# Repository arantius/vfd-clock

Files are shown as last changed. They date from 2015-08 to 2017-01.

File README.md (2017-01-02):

A six digit clock based on the IV-22 Vacuum Fluorescent Display tube.

A learning project for me, using vacuum fluorescent display tubes and the STM32 processor for the first time.

I personally built one of these, and ended up with lots of spare parts.
I sold a _very limited_ number of kits, made up mostly of those spares.
I have no plans to assemble nor sell any further kits.
If you are interested in building this clock yourself, check out the Bill of Materials below, and the issues tab.

# Bill of Materials

| Part | Reference(s) | Value | Example Manufacturer Part Number |
| ---- | --- | ----- | --- |
| Battery Holder | BT1 | n/a | BU2032SM-BT-GTR |
| Chip Capacitor (0603) | C1, C2 | 4pF | - |
| Electrolytic Capacitor | C3, C4, C5, C6 | 47μF | 25YXF47MEFC5X11 |
| Chip Capacitor (0603) | C7 | 330pF | n/a |
| DC Jack | CON2 | - | EJ508A |
| DC Plug | - | - | PP3-002A |
| Diode | D1 | - | STPS130A |
| Inductor | L1 | 68μH | RCH8011NP-680L |
| Transistor | Q1, Q2 | - | MMBT4403LT1G |
| Resistor | R1 | 0.22Ω | LR1LJR22 |
| Chip Resistor (0603) | R2 | 12.4kΩ | - |
| Chip Resistor (0603) | R3 | 41.2kΩ | - |
| Chip Resistor (0603) | R4, R5 | 1kΩ | - |
| Variable Resistor | RV1 | 22kΩ | PVA2A223A01R00 [#1](https://github.com/arantius/vfd-clock/issues/1) |
| Piezo Speaker | SP1 | - | AT-1224-TWT-5V-2-R [#2](https://github.com/arantius/vfd-clock/issues/2) |
| Tactile Switch | SW1, SW2, SW3, SW4 | - | FSM6JSMA |
| Microcontroller | U1 | Maple Mini | - |
| 7-Segment Driver (16-SOIC) | U2, U3, U4, U5, U6, U7 | - | CD4056BM96 |
| Boost Regulator (8-SOIC) | U8 | - | MC34063ACD-TR |
| Volt Level Shifter (16-TSSOP) | U9, U10 | - | CD4504BPWR |
| VFD Display Tube | V1, V2, V3, V4, V5, V6 | - | IV-22 (a.k.a. IN-22, IИ-22) |
| Watch Crystal | X1 | 32.7680kHz | CFS-20632768DZBB |
| Optional GPS | - | - | NEO-6M |

Notes:
 * The official [Baite store on Aliexpress ](https://www.aliexpress.com/store/product/x/213957_1400682373.html) is a reliable source of cheap clone Maple Mini boards.
 * You'll also need 72 single-pin sockets for the tubes, these are most commonly/affordably available on eBay.  Look for "nixie pin socket".  (They're $0.20 each from DigiKey, but as low as $0.05 each in quantity from eBay.)  These sockets raise the tube off the board so that the vaccum seal "nipple" has some room.  Plus the ability to remove and replace tubes is nice!
 * The optional GPS module, if used, should have an 0.1" four pin header of: Vcc, RX, TX, GND in that order.  I used a "Ublox NEO-6M" module.
 * The battery (and its) holder is optional.  If you don't mind losing the time when you unplug you don't need it.

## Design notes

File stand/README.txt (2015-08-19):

For most uses, "Leg.svg" can simply be laser cut twice.  (But this is not
yet tested...)

The "Leg_Con2.svg" is a second shape specifically meant to fit over the power
cord connected to CON2, instead of CON1.  Since this connector came out of
a Dell laptop, you're probably using the standard barrel CON1 and can thus
ignore this file.

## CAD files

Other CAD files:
stand/VFD Clock Stand.skp

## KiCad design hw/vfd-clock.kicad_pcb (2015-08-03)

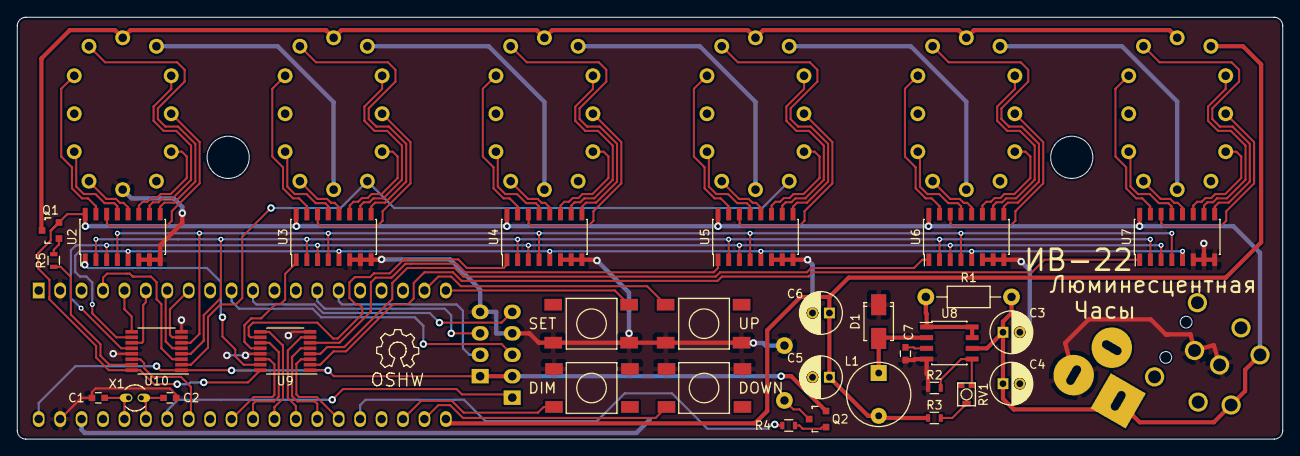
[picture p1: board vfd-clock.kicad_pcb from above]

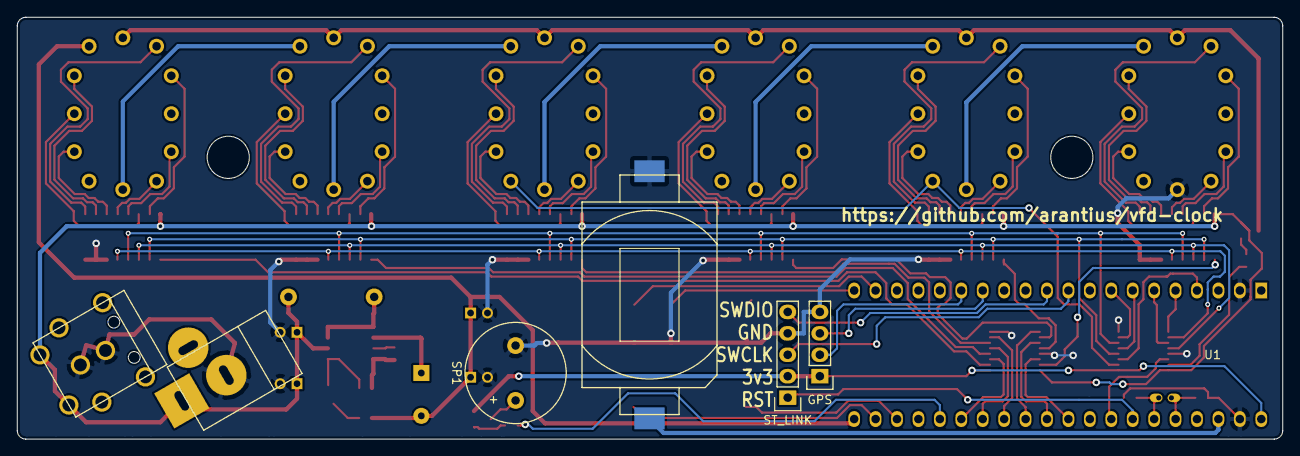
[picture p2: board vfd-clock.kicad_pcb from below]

Board: 2 copper layers, 150.0 x 50.0 mm, 46 parts (7 on the bottom side), 97 nets.

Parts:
BT1: COIN_BATT; BATT2032-1060TR
C1, C2: 4p; C_0603
C3, C4, C5, C6: 47u; C_Radial_D5_L11_P2
C7: 330p; C_0603
CON1: BARREL_JACK_2; JACK_ALIM
CON2: BARREL_JACK_2; OCT_JACK
D1: DIODESCH; Diode-SMA_Standard
L1: 68u; INDUCTOR_V
M1, M2: MountingHole_4-5mm; MountingHole_5mm
P1: ST_LINK; Pin_Header_Straight_1x05
P2: GPS; Pin_Header_Straight_1x04
Q1, Q2: PNP; MMBT4403L
R1: 0.22; Resistor_Horizontal_RM10mm
R2: 12.4k; R_0603
R3: 54.9k; R_0603
R4, R5: 1k; R_0603
RV1: 4k7; PVA2_POT
SP1: SPEAKER; AT-1224-TWT
SW1: SET; SMD_TACT_6mm
SW2: UP; SMD_TACT_6mm
SW3: DOWN; SMD_TACT_6mm
SW4: DIM; SMD_TACT_6mm
U1: Maple_Mini_(BTE14-07)
U2, U3, U4, U5, U6, U7: CD4056; SOIC-16_3.9x9.9mm_Pitch1.27mm
U8: MC34063; SOIC-8_3.9x4.9mm_Pitch1.27mm
U9, U10: CD4504; TSSOP-16_4.4x5mm_Pitch0.65mm
V1, V2, V3, V4, V5, V6: IV-22; DISP_IV-22_1PIN_SOCKET
X1: CRYSTAL; Crystal_Round_Vertical_3mm_BigPad

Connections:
/3v3: P1.2, P2.1, Q2.1, U1.40, U9.1, U10.1
/7v2: C5.1, C6.1, L1.2, R3.2, U1.21, V6.1
/19v5: C3.1, C4.1, CON1.1, CON2.1, Q1.1, R1.1, U2.16, U3.16, U4.16, U5.16, U6.16, U7.16, U8.6, U9.16, U10.16
/A1: U2.9, V1.11
/A2: U3.9, V2.11
/A3: U4.9, V3.11
/A4: U5.9, V4.11
/A5: U6.9, V5.11
/A6: U7.9, V6.11
/B1: U2.10, V1.2
/B2: U3.10, V2.2
/B3: U4.10, V3.2
/B4: U5.10, V4.2
/B5: U6.10, V5.2
/B6: U7.10, V6.2
/BTN_DIM: SW4.1, U1.23
/BTN_DN: SW3.1, U1.22
/BTN_SET: SW1.1, U1.20
/BTN_UP: SW2.1, U1.19
/BUZ: R4.2, U1.25
/C1: U2.11, V1.4
/C2: U3.11, V2.4
/C3: U4.11, V3.4
/C4: U5.11, V4.4
/C5: U6.11, V5.4
/C6: U7.11, V6.4
/D1: U2.12, V1.7
/D2: U3.12, V2.7
/D3: U4.12, V3.7
/D4: U5.12, V4.7
/D5: U6.12, V5.7
/D6: U7.12, V6.7
/DAH: U2.5, U3.5, U4.5, U5.5, U6.5, U7.5, U10.10
/DAL: U1.5, U10.9
/DBH: U2.3, U3.3, U4.3, U5.3, U6.3, U7.3, U10.12
/DBL: U1.6, U10.11
/DCH: U2.2, U3.2, U4.2, U5.2, U6.2, U7.2, U10.4
/DCL: U1.7, U10.5
/DDH: U2.4, U3.4, U4.4, U5.4, U6.4, U7.4, U10.6
/DDL: U1.8, U10.7
/DPH: U10.2, V2.5, V4.5
/DPL: U1.4, U10.3
/E1: U2.13, V1.8
/E2: U3.13, V2.8
/E3: U4.13, V3.8
/E4: U5.13, V4.8
/E5: U6.13, V5.8
/E6: U7.13, V6.8
/F1: U2.15, V1.10
/F2: U3.15, V2.10
/F3: U4.15, V3.10
/F4: U5.15, V4.10
/F5: U6.15, V5.10
/F6: U7.15, V6.10
/FIL1: V1.1, V2.6
/FIL2: V2.1, V3.6
/FIL3: V3.1, V4.6
/FIL4: V4.1, V5.6
/FIL5: V5.1, V6.6
/G1: U2.14, V1.3
/G2: U3.14, V2.3
/G3: U4.14, V3.3
/G4: U5.14, V4.3
/G5: U6.14, V5.3
/G6: U7.14, V6.3
/GND: BT1.2, C1.2, C2.2, C3.2, C4.2, C5.2, C6.2, C7.1, CON1.2, CON2.2, D1.1, P1.4, P2.4, R2.2, SP1.2, SW1.2, SW2.2, SW3.2, SW4.2, U1.2, U1.39, U2.6, U2.7, U2.8, U3.6, U3.7, U3.8, U4.6, U4.7, U4.8, U5.6, U5.7, U5.8, U6.6, U6.7, U6.8, U7.6, U7.7, U7.8, U8.4, U9.8, U9.13, U10.8, U10.13, V1.6
/GPS_RX: P2.2, U1.15
/GPS_TX: P2.3, U1.14
/GRID: Q1.3, V1.12, V2.12, V3.12, V4.12, V5.12, V6.12
/GRIDH: R5.2, U10.15
/GRIDL: U1.33, U10.14
/REG_HI: R1.2, U8.1, U8.7, U8.8
/RST: P1.1, U1.34
/STROBE1H: U2.1, U9.15
/STROBE1L: U1.31, U9.14
/STROBE2H: U3.1, U9.12
/STROBE2L: U1.30, U9.11
/STROBE3H: U4.1, U9.10
/STROBE3L: U1.29, U9.9
/STROBE4H: U5.1, U9.6
/STROBE4L: U1.28, U9.7
/STROBE5H: U6.1, U9.4
/STROBE5L: U1.27, U9.5
/STROBE6H: U7.1, U9.2
/STROBE6L: U1.26, U9.3
/SWCLK: P1.3, U1.10
/SWDIO: P1.5, U1.11
/Vbat: BT1.1, U1.38
unnamed: C1.1, U1.36, X1.1
unnamed: C2.1, U1.35, X1.2
unnamed: C7.2, U8.3
unnamed: D1.2, L1.1, U8.2
unnamed: Q1.2, R5.1
unnamed: Q2.2, R4.1
unnamed: Q2.3, SP1.1
unnamed: R2.1, RV1.1, U8.5
unnamed: R3.1, RV1.2

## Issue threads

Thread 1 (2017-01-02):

The trimpot is tiny

arantius, 2017-01-02:
As part of the voltage regulator circuit, there is a variable resistor/trimpot.  I sourced this part sight unseen across the internet, and the selected part is _really tiny_.  So small it's hard to get a screwdriver to turn it.  A bigger trimpot would be nice.

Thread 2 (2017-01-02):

The speaker doesn't fit.

arantius, 2017-01-02:
The footprint in the PCB and the selected piezo speaker aren't quite the same size.  The PCB holes are just a bit too far apart for part `AT-1224-TWT-5V-2-R`'s pins to fit correctly.

The PCB footprint should be fixed, or a part with pins that line up should be selected.

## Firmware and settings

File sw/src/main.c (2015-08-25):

/*
Copyright (C) 2015  Anthony Lieuallen

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
You should have received a copy of the GNU General Public License
along with this program.  If not, see <http://www.gnu.org/licenses/>.
*/

#include <stdio.h>
#include <stdlib.h>
#include <string.h>
#include <time.h>

#include "diag/Trace.h"
#include "misc.h"
#include "stm32f10x.h"
#include "stm32f10x_bkp.h"
#include "stm32f10x_gpio.h"
#include "stm32f10x_pwr.h"
#include "stm32f10x_rcc.h"
#include "stm32f10x_rtc.h"
#include "stm32f10x_tim.h"

// \\ // \\ // \\ // \\ // \\ // \\ // \\ // \\ // \\ // \\ // \\ // \\ // \\ //

// Maple's built in LED.
#define LED_PORT GPIOB
#define LED_PIN GPIO_Pin_1

// Maple's built in button.
#define BTN_MAPLE_PIN GPIO_Pin_8

#define BTN_PORT GPIOB
#define BTN_DIM_PIN GPIO_Pin_10
#define BTN_SET_PIN GPIO_Pin_12
#define BTN_UP_PIN GPIO_Pin_13
#define BTN_DN_PIN GPIO_Pin_11
typedef enum {BTN_NONE, BTN_MAPLE, BTN_UP, BTN_DOWN, BTN_DIM, BTN_SET} ButtonId;
#define BTN_ALL_PINS (BTN_MAPLE_PIN|BTN_DIM_PIN|BTN_SET_PIN|BTN_UP_PIN|BTN_DN_PIN)

#define DATA_PORT GPIOB
#define DA_PIN GPIO_Pin_6
#define DB_PIN GPIO_Pin_5
#define DC_PIN GPIO_Pin_4
#define DD_PIN GPIO_Pin_3
#define DATA_PIN_MASK (GPIO_Pin_6|GPIO_Pin_5|GPIO_Pin_4|GPIO_Pin_3)

#define DP_PORT GPIOB  // Decimal point.
#define DP_PIN GPIO_Pin_7

#define STROBE_PORT GPIOA
#define STROBE1_PIN GPIO_Pin_2
#define STROBE2_PIN GPIO_Pin_3
#define STROBE3_PIN GPIO_Pin_4
#define STROBE4_PIN GPIO_Pin_5
#define STROBE5_PIN GPIO_Pin_6
#define STROBE6_PIN GPIO_Pin_7
#define STROBE_ALL_PINS ( \
    STROBE1_PIN | STROBE2_PIN | STROBE3_PIN \
    | STROBE4_PIN | STROBE5_PIN | STROBE6_PIN)

#define GRID_PORT GPIOA
#define GRID_PIN GPIO_Pin_0
#define BUZ_PORT GPIOB
#define BUZ_PIN GPIO_Pin_0

#define DIGIT_L 10
#define DIGIT_H 11
#define DIGIT_P 12
#define DIGIT_A 13
#define DIGIT_DASH 14
#define DIGIT_BLANK 15

#define BACKUP_MARKER 0x4ca7
#define CR_LF "\x0D\x0A"

// \\ // \\ // \\ // \\ // \\ // \\ // \\ // \\ // \\ // \\ // \\ // \\ // \\ //

volatile uint8_t gBlinkStatus = 0;
volatile uint8_t gBlinkPos = 0;
volatile uint16_t gBlinkTick = 0;
volatile uint8_t gButtonDebounce = 0;
volatile uint8_t gButtonPending = 0;
volatile uint8_t gButtonPressed = 0;
TIM_OCInitTypeDef gBuzOc;
volatile uint16_t gDpTick = 0;
TIM_OCInitTypeDef gGridOc;
uint8_t gSecondFlag = 0;
time_t gSeconds = 0;

#define USART_BUF_SIZE 128
char gUsartBuf[USART_BUF_SIZE];
volatile uint8_t gUsartIdx = 0;

uint8_t gGpsAvailable = 0;
char gGpsLine[USART_BUF_SIZE];
time_t gGpsNextPoll = 0;
uint8_t gSettingUtcOffset = 0;
#define UTC_OFFSET_ADJUST 1800
int32_t gUtcOffset = 0;

// Since the data pins' order are reversed as compared to the bits of the
// GPIOB register, we need to reverse (i.e. 0b0001 -> 0b1000) their order
// to match, in order to do an atomic write of all four.
const uint8_t gDataBitsReversed[16] = {
    0b0000, 0b1000, 0b0100, 0b1100, 0b0010, 0b1010, 0b0110, 0b1110,
    0b0001, 0b1001, 0b0101, 0b1101, 0b0011, 0b1011, 0b0111, 0b1111};
// Amount to change the current time by, when setting this digit up/down.
const uint16_t gSettingChange[6] = {0, 3600, 600, 60, 10, 1};
const uint16_t gStrobePins[6] = {
    STROBE1_PIN, STROBE2_PIN, STROBE3_PIN,
    STROBE4_PIN, STROBE5_PIN, STROBE6_PIN};

// \\ // \\ // \\ // \\ // \\ // \\ // \\ // \\ // \\ // \\ // \\ // \\ // \\ //

void gpsTxChar(char c) {
  USART_SendData(USART1, c);
  while(USART_GetFlagStatus(USART1, USART_FLAG_TC) == RESET) { }
}

void gpsTx(const char *cmd) {
  uint8_t chk = 0;
  uint16_t i = 0;
  char c = 0;

  gpsTxChar('$');
  for (i = 0; (c = cmd[i]); i++) {
    USART_SendData(USART1, c);
    chk ^= c;
    while(USART_GetFlagStatus(USART1, USART_FLAG_TC) == RESET) { }
  }

  char hexChk[3];
  sprintf(hexChk, "%02X", chk);
  gpsTxChar('*');
  gpsTxChar(hexChk[0]);
  gpsTxChar(hexChk[1]);
  gpsTxChar('\r');
  gpsTxChar('\n');
}

void gpsSetPushFreq(const char *cmdName, uint16_t freq) {
  char cmd[32];
  sprintf(cmd, "PUBX,40,%s,0,%d,0,0", cmdName, freq);
  gpsTx(cmd);
}

// \\ // \\ // \\ // \\ // \\ // \\ // \\ // \\ // \\ // \\ // \\ // \\ // \\ //

void initGpio() {
  // We have to 1) Enable the GPIO clocks.
  RCC_APB2PeriphClockCmd(RCC_APB2Periph_GPIOA | RCC_APB2Periph_GPIOB, ENABLE);
  // 2) Enable AFIO (we want it later for timers and interrupts, and ...)
  RCC_APB2PeriphClockCmd(RCC_APB2Periph_AFIO, ENABLE);
  // 3) Disable JTAG (... which must be after AFIO enable) to release its pins.
  GPIO_PinRemapConfig(GPIO_Remap_SWJ_JTAGDisable, ENABLE);

  GPIO_InitTypeDef GPIO_InitStructure;
  GPIO_InitStructure.GPIO_Speed = GPIO_Speed_10MHz;

  // Port A, output.
  GPIO_InitStructure.GPIO_Pin = STROBE1_PIN | STROBE2_PIN | STROBE3_PIN
      | STROBE4_PIN | STROBE5_PIN | STROBE6_PIN;
  GPIO_InitStructure.GPIO_Mode = GPIO_Mode_Out_PP;  // Push-pull output.
  GPIO_Init(GPIOA, &GPIO_InitStructure);

  // Port B, input.
  GPIO_InitStructure.GPIO_Pin = BTN_MAPLE_PIN; // Maple's built in button.
  GPIO_InitStructure.GPIO_Mode = GPIO_Mode_IPD;  // Input, pull down.
  GPIO_Init(GPIOB, &GPIO_InitStructure);
  GPIO_InitStructure.GPIO_Pin =
      BTN_DIM_PIN | BTN_SET_PIN | BTN_UP_PIN | BTN_DN_PIN;
  GPIO_InitStructure.GPIO_Mode = GPIO_Mode_IPU;  // Input, pull up.
  GPIO_Init(GPIOB, &GPIO_InitStructure);
  // Port B, output.
  GPIO_InitStructure.GPIO_Pin = LED_PIN // Maple's built in LED.
      | DA_PIN | DB_PIN | DC_PIN | DD_PIN | DP_PIN;
  GPIO_InitStructure.GPIO_Mode = GPIO_Mode_Out_PP;  // Push-pull output.
  GPIO_Init(GPIOB, &GPIO_InitStructure);
}


// Define either _INT or _EXT to select low-speed clock source.
#define CLK_SRC_EXT

// AN2821: Clock/calendar implementation on the STM32F10xxx microcontroller RTC
// http://www.st.com/web/en/resource/technical/document/application_note/CD00207941.pdf
void initRtc() {
  RCC_APB1PeriphClockCmd(RCC_APB1Periph_BKP|RCC_APB1Periph_PWR, ENABLE);
  PWR_BackupAccessCmd(ENABLE);

  #if defined(CLK_SRC_EXT)
    RCC_LSEConfig(RCC_LSE_ON);
    for (uint16_t i = 0; i < 1<<15; i++) {
      if (RCC_GetFlagStatus(RCC_FLAG_LSERDY) == SET) {
        trace_printf("LSE clock became ready at iteration %d.\n", i);
        break;
      }
    }
    RCC_RTCCLKConfig(RCC_RTCCLKSource_LSE);
    RTC_WaitForLastTask();
  #elif defined(CLK_SRC_INT)
    RCC_LSICmd(ENABLE);
    for (uint16_t i = 0; i < 1<<15; i++) {
      if (RCC_GetFlagStatus(RCC_FLAG_LSIRDY) == SET) {
        trace_printf("LSI clock became ready at iteration %d.\n", i);
        break;
      }
    }
    RCC_RTCCLKConfig(RCC_RTCCLKSource_LSI);
    RTC_WaitForLastTask();
  #endif
  RCC_RTCCLKCmd(ENABLE);
  RTC_WaitForSynchro();
  RTC_WaitForLastTask();

  // This must come after WaitForSynchro().
  #if defined(CLK_SRC_EXT)
    RTC_SetPrescaler(32768);  // Watch crystal.
    RTC_WaitForLastTask();
  #elif defined(CLK_SRC_INT)
    // RM0041, page 74: "The clock frequency is around 40kHz."
    RTC_SetPrescaler(40500);
    RTC_WaitForLastTask();
  #endif

  RTC_ClearITPendingBit(RTC_IT_SEC);
  RTC_ITConfig(RTC_IT_ALR|RTC_IT_OW, DISABLE);
  RTC_ITConfig(RTC_IT_SEC, ENABLE);
  RTC_WaitForLastTask();

  PWR_BackupAccessCmd(DISABLE);

  NVIC_InitTypeDef NVIC_InitStructure = {
    .NVIC_IRQChannel = RTC_IRQn,
    .NVIC_IRQChannelPreemptionPriority = 1,
    .NVIC_IRQChannelSubPriority = 2,
    .NVIC_IRQChannelCmd = ENABLE,
  };
  NVIC_Init(&NVIC_InitStructure);
}


void initTimer() {
  // TIM3 clock enable
  RCC_APB1PeriphClockCmd(RCC_APB1Periph_TIM2 | RCC_APB1Periph_TIM3, ENABLE);

  // Enable both pins as alternate function.
  GPIO_InitTypeDef GPIO_InitStructure;
  GPIO_InitStructure.GPIO_Speed = GPIO_Speed_10MHz;
  GPIO_InitStructure.GPIO_Mode = GPIO_Mode_AF_PP;
  GPIO_InitStructure.GPIO_Pin = GRID_PIN;
  GPIO_Init(GRID_PORT, &GPIO_InitStructure);
  GPIO_InitStructure.GPIO_Pin = BUZ_PIN;
  GPIO_Init(BUZ_PORT, &GPIO_InitStructure);

  // Time base configuration;
  TIM_TimeBaseInitTypeDef  TIM_TimeBaseStructure;
  TIM_TimeBaseStructure.TIM_ClockDivision = TIM_CKD_DIV1;
  TIM_TimeBaseStructure.TIM_CounterMode = TIM_CounterMode_Up;

  // Grid PWM is on PA0 (D11), this is timer 2 channel 1.
  // 72MHz system clock / 1800 / 80 = 500Hz
  TIM_TimeBaseStructure.TIM_Period = 80;
  TIM_TimeBaseStructure.TIM_Prescaler = 1800;
  TIM_TimeBaseInit(TIM2, &TIM_TimeBaseStructure);
  gGridOc.TIM_OCMode = TIM_OCMode_PWM1;
  gGridOc.TIM_OCPolarity = TIM_OCPolarity_High;
  gGridOc.TIM_OutputState = TIM_OutputState_Enable;
  gGridOc.TIM_Pulse = 40;  // 40 of period 80 = 50% duty
  TIM_OC1Init(TIM2, &gGridOc);
  TIM_OC1PreloadConfig(TIM2, TIM_OCPreload_Enable);
  TIM_ARRPreloadConfig(TIM2, ENABLE);  // ARR = Auto Reload Register
  TIM_Cmd(TIM2, ENABLE);

  // Buzzer PWM is on PB0 (D3), this is timer 3 channel 3.
  // 72MHz system clock / 1800 / 67 = ~600 Hz.
  TIM_TimeBaseStructure.TIM_Period = 67;
  TIM_TimeBaseStructure.TIM_Prescaler = 1800;
  TIM_TimeBaseInit(TIM3, &TIM_TimeBaseStructure);
  gBuzOc.TIM_OCMode = TIM_OCMode_PWM1;
  gBuzOc.TIM_OCPolarity = TIM_OCPolarity_High;
  gBuzOc.TIM_OutputState = TIM_OutputState_Enable;
  gBuzOc.TIM_Pulse = 30;
  TIM_OC3Init(TIM3, &gBuzOc);
  TIM_OC3PreloadConfig(TIM3, TIM_OCPreload_Enable);
  TIM_ARRPreloadConfig(TIM3, ENABLE);  // ARR = Auto Reload Register
  TIM_Cmd(TIM3, ENABLE);
}


void initUart() {
  RCC_APB2PeriphClockCmd(
      RCC_APB2Periph_USART1 | RCC_APB2Periph_GPIOA | RCC_APB2Periph_AFIO,
      ENABLE);

  GPIO_InitTypeDef GPIO_InitStructure;
  GPIO_StructInit(&GPIO_InitStructure);

  // Transmit pin.
  GPIO_InitStructure.GPIO_Pin = GPIO_Pin_9,
  GPIO_InitStructure.GPIO_Mode = GPIO_Mode_AF_PP;
  GPIO_Init(GPIOA, &GPIO_InitStructure);

  // Receive pin.
  GPIO_InitStructure.GPIO_Pin = GPIO_Pin_10;
  GPIO_InitStructure.GPIO_Mode = GPIO_Mode_IN_FLOATING;
  GPIO_Init(GPIOA, &GPIO_InitStructure);

  // Default clock structure works for us.
  USART_ClockInitTypeDef USART_ClockInitStructure;
  USART_ClockStructInit(&USART_ClockInitStructure);
  USART_ClockInit(USART1, &USART_ClockInitStructure);

  // Default USART structure works for us.
  USART_InitTypeDef USART_InitStructure;
  USART_StructInit(&USART_InitStructure);
  USART_Init(USART1, &USART_InitStructure);

  USART_Cmd(USART1, ENABLE);

//  // Disable data pushes from GPS.
//  usartTx("$PUBX,40,GGA,0,0,0,0*5A\r\n");
//  usartTx("$PUBX,40,GGA,0,0,0,0*5A\r\n");  // Repeat first; timing work around.
//  usartTx("$PUBX,40,GLL,0,0,0,0*5C\r\n");
//  usartTx("$PUBX,40,GSA,0,0,0,0*4E\r\n");
//  usartTx("$PUBX,40,GSV,0,0,0,0*59\r\n");
//  usartTx("$PUBX,40,RMC,0,0,0,0*47\r\n");
//  usartTx("$PUBX,40,VTG,0,0,0,0*5E\r\n");
//  // Keep just the recommended minimum flowing, slowly.
//  usartTx("$PUBX,40,GGA,0,15,0,0*6E\r\n");
//  usartTx("$PUBX,40,GGA,0,15,0,0*6E\r\n");  // Repeat first; timing work around.
//  usartTx("$PUBX,40,GLL,0,15,0,0*68\r\n");
//  usartTx("$PUBX,40,GSA,0,15,0,0*7A\r\n");
//  usartTx("$PUBX,40,GSV,0,15,0,0*6D\r\n");
//  usartTx("$PUBX,40,RMC,0,15,0,0*73\r\n");
//  usartTx("$PUBX,40,VTG,0,15,0,0*6A\r\n");

  // The first character is sometimes (always?) dropped, so send a few
  // buffer characters that can be safely discarded.
  gpsTxChar('\r'); gpsTxChar('\n');
  gpsTxChar('\r'); gpsTxChar('\n');

  // Disable all data pushes from GPS.
  gpsSetPushFreq("DTM", 0);
  gpsSetPushFreq("GBS", 0);
  gpsSetPushFreq("GGA", 0);
  gpsSetPushFreq("GLL", 0);
  gpsSetPushFreq("GPQ", 0);
  gpsSetPushFreq("GRS", 0);
  gpsSetPushFreq("GSA", 0);
  gpsSetPushFreq("GST", 0);
  gpsSetPushFreq("GSV", 0);
  gpsSetPushFreq("RMC", 0);
  gpsSetPushFreq("THS", 0);
  gpsSetPushFreq("VTG", 0);
  // Except the one which tells us what time it is.
  gpsSetPushFreq("ZDA", 2);

  // Now that it won't be noisy, enable the RX interrupt.
  NVIC_InitTypeDef NVIC_InitStructure = {
    .NVIC_IRQChannel = USART1_IRQn,
    .NVIC_IRQChannelPreemptionPriority = 1,
    .NVIC_IRQChannelSubPriority = 1,
    .NVIC_IRQChannelCmd = ENABLE,
  };
  NVIC_Init(&NVIC_InitStructure);
  USART_ITConfig(USART1, USART_IT_RXNE, ENABLE);
}

// \\ // \\ // \\ // \\ // \\ // \\ // \\ // \\ // \\ // \\ // \\ // \\ // \\ //

void RTC_IRQHandler(void) {
  if (RTC_GetFlagStatus(RTC_FLAG_SEC) != RESET) {
    RTC_ClearFlag(RTC_FLAG_SEC);
    gSecondFlag = 1;
    gSeconds = RTC_GetCounter();
  }
}


void SysTick_Handler(void) {
  gBlinkTick++;
  if (gBlinkTick > 125) {
    gBlinkTick = 0;
    gBlinkStatus = !gBlinkStatus;
  }

  uint8_t btnPressed = 0;
  uint16_t btns = GPIO_ReadInputData(BTN_PORT) & BTN_ALL_PINS;
  if ((btns & BTN_MAPLE_PIN) == BTN_MAPLE_PIN) btnPressed = BTN_MAPLE;
  else if ((btns & BTN_DIM_PIN) == 0) btnPressed = BTN_DIM;
  else if ((btns & BTN_DN_PIN) == 0) btnPressed = BTN_DOWN;
  else if ((btns & BTN_UP_PIN) == 0) btnPressed = BTN_UP;
  else if ((btns & BTN_SET_PIN) == 0) btnPressed = BTN_SET;
  if (btnPressed && gButtonPending == btnPressed) {
    if (gButtonDebounce > 10) {
      // Button already activated, still held, do nothing.
    } else if (gButtonDebounce == 10) {
      // Transition!  Set pressed button.
      gButtonPressed = btnPressed;
      gButtonDebounce++;
    } else {
      gButtonDebounce++;
    }
  } else {
    gButtonDebounce = 0;
    gButtonPending = btnPressed;
  }

  if (gDpTick > 0) {
    gDpTick--;
    if (gDpTick == 0) {
      GPIO_WriteBit(DP_PORT, DP_PIN, RESET);
    }
  }
}


void USART1_IRQHandler(void) {
  if (USART_GetFlagStatus(USART1, USART_FLAG_RXNE) == RESET) return;

  // Emergency fall back, wrap around if we've gone too far.
  if (gUsartIdx >= (USART_BUF_SIZE - 2)) {
    gUsartIdx = 0;
  }

  uint16_t usartData = USART_ReceiveData(USART1);
  gUsartBuf[gUsartIdx] = usartData & 0xFF;

  if (gUsartBuf[gUsartIdx] == '\n' && gUsartBuf[gUsartIdx-1] == '\r') {
    memcpy(gGpsLine, gUsartBuf, gUsartIdx - 1);
    gGpsLine[gUsartIdx - 1] = 0x00;
    gUsartIdx = 0;
  } else {
    gUsartIdx += 1;
  }
}

// \\ // \\ // \\ // \\ // \\ // \\ // \\ // \\ // \\ // \\ // \\ // \\ // \\ //

/**
 * Set all four data lines to the 4 LS bits of val.
 *
 * Values 0 through 9 are those digits; 10 through 14 are respectively
 * L H P A -, while 15 is blank.
 */
void setDataLines(uint8_t val) {
  GPIO_Write(
      GPIOB, (GPIOB->ODR & ~DATA_PIN_MASK) | (gDataBitsReversed[val] << 3) );
}


/** Turn exactly zero or one strobe lines on. */
void setStrobeLines(uint8_t strobeLine) {
  GPIO_ResetBits(STROBE_PORT, STROBE_ALL_PINS);
  if (strobeLine > 0) {
    GPIO_SetBits(STROBE_PORT, gStrobePins[strobeLine - 1]);
  }
}


void setRtcTime(time_t current) {
  PWR_BackupAccessCmd(ENABLE);
  RTC_WaitForLastTask();
  RTC_SetCounter(current);
  RTC_WaitForLastTask();
  PWR_BackupAccessCmd(DISABLE);
  RTC_WaitForLastTask();
  gSecondFlag = 1;
}


/** Busy loop a delay for the CD4056B while strobe is high. */
inline void strobeWait() {
  // Chip wants strobe high for 35-220 ns, depending on Vdd.  More time
  // when driven at lower voltages.  At 15v, max is 70ns, and we're above 15.
  // Let's be generous, wait at least 100ns.  At 72MHz a clock cycle is
  // 13.89ns; eight of them is enough to consistently measure high for over
  // 100ns as per my logic analyzer (sampling at 24MHz), Release build.
  asm("NOP");
  asm("NOP");
  asm("NOP");
  asm("NOP");
  asm("NOP");
  asm("NOP");
  asm("NOP");
  asm("NOP");
}

void pulseStrobeLine(uint8_t strobeLine) {
  setStrobeLines(strobeLine);
  strobeWait();
  setStrobeLines(0);
}

void setDisplay(uint8_t digits[]) {
  setStrobeLines(0);
  strobeWait();
  setDataLines(digits[0]); pulseStrobeLine(1);
  setDataLines(digits[1]); pulseStrobeLine(2);
  setDataLines(digits[2]); pulseStrobeLine(3);
  setDataLines(digits[3]); pulseStrobeLine(4);
  setDataLines(digits[4]); pulseStrobeLine(5);
  setDataLines(digits[5]); pulseStrobeLine(6);
  setDataLines(0);
}

// \\ // \\ // \\ // \\ // \\ // \\ // \\ // \\ // \\ // \\ // \\ // \\ // \\ //

void backupSave() {
  PWR_BackupAccessCmd(ENABLE);
  BKP_ClearFlag();

  BKP_WriteBackupRegister(BKP_DR1, BACKUP_MARKER);
  BKP_WriteBackupRegister(BKP_DR2, (gUtcOffset >> 16) & 0xFFFF);
  BKP_WriteBackupRegister(BKP_DR3, gUtcOffset & 0xFFFF);
  BKP_WriteBackupRegister(BKP_DR4, gGridOc.TIM_Pulse);

  PWR_BackupAccessCmd(DISABLE);
}


void backupLoad() {
  if (BACKUP_MARKER != BKP_ReadBackupRegister(BKP_DR1)) {
    // The magic marker isn't set in register 1, ignore.
    return;
  }

  gUtcOffset = (BKP_ReadBackupRegister(BKP_DR2) << 16)
      + BKP_ReadBackupRegister(BKP_DR3);
  gGridOc.TIM_Pulse = BKP_ReadBackupRegister(BKP_DR4);
}

// \\ // \\ // \\ // \\ // \\ // \\ // \\ // \\ // \\ // \\ // \\ // \\ // \\ //

/// Given gButtonPressed, update state accordingly.
void handleButtonPress() {
  switch (gButtonPressed) {
  case BTN_NONE:
    break;
  case BTN_MAPLE:
    trace_puts("Maple button!");
    gGpsAvailable = !gGpsAvailable;
    break;
  case BTN_SET:
    if (gGpsAvailable) {
      gSettingUtcOffset = !gSettingUtcOffset;
      trace_printf("Set button; setting utc offset=%d\n", gSettingUtcOffset);
      gSecondFlag |= !gSettingUtcOffset;
    } else {
      gBlinkPos += 1;
      if (gBlinkPos > 5) {
        gBlinkPos = 0;
        gSecondFlag = 1;  // Force logic loop to display digits.
      }
      trace_printf("Set button; new pos %d\n", gBlinkPos);
    }
    break;
  case BTN_DIM:
    gGridOc.TIM_Pulse += 10;
    gGridOc.TIM_Pulse %= 80;
    TIM_OC1Init(TIM2, &gGridOc);
    trace_printf("Dim button; pulse now %d of 80.\n", gGridOc.TIM_Pulse);
    backupSave();
    break;
  case BTN_UP:
    trace_puts("Up button!");
    if (gSettingUtcOffset) {
      gUtcOffset += UTC_OFFSET_ADJUST;
      if (gUtcOffset > (14 * 3600)) gUtcOffset = -12 * 3600;
      trace_printf("utc offset now=%d\n", gUtcOffset);
      backupSave();
    } else {
      gSeconds = RTC_GetCounter() + gSettingChange[gBlinkPos];
      setRtcTime(gSeconds);
    }
    gSecondFlag = 1;
    break;
  case BTN_DOWN:
    trace_puts("Down button!");
    if (gSettingUtcOffset) {
      gUtcOffset -= UTC_OFFSET_ADJUST;
      if (gUtcOffset < (-12 * 3600)) gUtcOffset = 14 * 3600;
      trace_printf("utc offset now=%d\n", gUtcOffset);
      backupSave();
    } else {
      gSeconds = RTC_GetCounter() - gSettingChange[gBlinkPos];
      setRtcTime(gSeconds);
    }
    gSecondFlag = 1;
    break;
  default:
    // No button pressed, ignore.
    break;
  }
  gButtonPressed = BTN_NONE;
}


/// Fill the digits array based on current state.
void handleDigits(uint8_t *digits, struct tm *t) {
  if (gSettingUtcOffset) {
    digits[0] = 0;
    if (gBlinkStatus) {
      memchr(digits + 1, DIGIT_BLANK, 5);
    } else {
      digits[1] = gUtcOffset < 0 ? DIGIT_DASH : DIGIT_BLANK;
      uint16_t dispHrs = abs(gUtcOffset / 3600);
      uint16_t dispMins = abs(gUtcOffset / 60) % 60;
      digits[2] = (dispHrs / 10) % 10;
      digits[3] = (dispHrs / 1) % 10;
      digits[4] = (dispMins / 10) % 10;
      digits[5] = (dispMins / 1) % 10;
    }
  } else {
    // TODO: Configurable 12/24 hour.
    uint8_t h = t->tm_hour;
    h %= 12; if (h == 0) h = 12;  // Cast 24->12 hour.
    digits[0] = h / 10;
    digits[1] = h % 10;
    digits[2] = t->tm_min / 10;
    digits[3] = t->tm_min % 10;
    digits[4] = t->tm_sec / 10;
    digits[5] = t->tm_sec % 10;
  }

  if (gBlinkPos > 0) {
    if (gBlinkStatus) {
      digits[gBlinkPos] = DIGIT_BLANK;
      // gBlinkPos of 1 means "hours"; blink both digits.
      if (gBlinkPos == 1) {
        digits[0] = DIGIT_BLANK;
      }
    }
    setDisplay(digits);
  } else if (gSettingUtcOffset) {
    setDisplay(digits);
  }
}
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
int main() {
  trace_puts(">>> VfdClock main() init");
  initGpio();
  initRtc();
  initTimer();
  initUart();
  SysTick_Config(72000);  // 1kHz
  trace_puts("<<< VfdClock main() init");

  GPIO_WriteBit(LED_PORT, LED_PIN, RESET);

  // Disable buzzer.
  GPIO_WriteBit(BUZ_PORT, BUZ_PIN, RESET);
  TIM_Cmd(TIM3, DISABLE);

  backupLoad();

  uint8_t digits[6] = {
      DIGIT_BLANK, DIGIT_DASH, DIGIT_DASH, DIGIT_DASH, DIGIT_DASH, DIGIT_BLANK};
  setDisplay(digits);

  gSeconds = RTC_GetCounter();

  time_t localtime;
  struct tm *t = gmtime(&gSeconds);

  // Logic loop.
  while (1) {
    // Read GPS data, if it exists.
    if (strlen(gGpsLine) > 0) {
      handleGpsLine();
    } else if (gGpsNextPoll < gSeconds) {
      gpsSetPushFreq("ZDA", 2);
    }

    handleDigits(digits, t);
    handleButtonPress();

    if (gSecondFlag) {
      gSecondFlag = 0;
      localtime = gSeconds + gUtcOffset;
      t = gmtime(&localtime);
      handleDigits(digits, t);
      setDisplay(digits);
      // Blink decimal point.
      GPIO_WriteBit(DP_PORT, DP_PIN, SET);
      gDpTick = 500;
    }
  }
}

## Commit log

2015-05-31 initial commit; with maple mini library component
    [vfd-clock.sch]
2015-05-31 add CD4504 level shifters
    [vfd-clock.sch]
2015-05-31 add CD4543
    [vfd-clock.sch]
2015-05-31 add IV-22
    [vfd-clock.sch]
2015-05-31 various bits of the schematic wired up
    [vfd-clock.sch]
2015-06-01 schematic progress, board positioning
    [vfd-clock.kicad_pcb, vfd-clock.sch]
2015-06-01 tubes, data bus: routed
    [vfd-clock.kicad_pcb, vfd-clock.sch]
2015-06-01 first fully routed revision
    [vfd-clock.kicad_pcb]
2015-06-01 second redundant power connector footprint
    (I expect to only ever populate one or the other.)
    [vfd-clock.kicad_pcb, vfd-clock.sch]
2015-06-01 add buttons to set time
    [vfd-clock.kicad_pcb, vfd-clock.sch]
2015-06-05 lots of rerouting, buttons, part switches
    surface mount!
    [vfd-clock.kicad_pcb, vfd-clock.sch]
2015-07-14 create 'hw' directory beside 'sw'
    [vfd-clock.kicad_pcb, vfd-clock.sch]
2015-07-15 Major hardware rework.
    With discrete voltage level shifters, buzzer, pins for a GPS module
    addon.
    [vfd-clock.kicad_pcb, vfd-clock.sch]
2015-07-15 Blinky project base.
    "New project" template from GNU Arm Eclipse plugins.
2015-07-15 rtc init? doesn't fire interrupts
    [main.c]
2015-07-15 more minimal, RTC interrupt fires
    way too often though???
2015-07-15 set counter value AND interrupt once per second!!!
2015-07-15 use mini's button to set a counter value
2015-07-15 interrupt handler only sets a few global vars
2015-07-15 Set RTC prescaler correctly.
    Add an extra #if branch because it has to come after WaitForSynchro()!
    [main.c]
2015-07-15 start to do button/display I/O
    Only thing that works for sure is the LED test
2015-07-16 various small tweaks
    including switch the VFD tube outline from silkscreen to fab layer
    [vfd-clock.kicad_pcb, vfd-clock.sch]
2015-07-16 Fix VFD pinout.
    [vfd-clock.kicad_pcb, vfd-clock.sch]
2015-07-16 VFD trace tweak, label font size
    [vfd-clock.kicad_pcb]
2015-07-17 last level shifter output lights decimal points
    specifically the 2nd and 4th, i.e. between the hours/minutes and
    minutes/seconds
    [vfd-clock.kicad_pcb, vfd-clock.sch]
2015-07-19 mount holes, tweaks to ground fill, gerbers
    [vfd-clock-B_Cu.gbl, vfd-clock-B_Mask.gbs, vfd-clock-B_Paste.gbp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]
2015-07-19 Sketchup framework for stand design
    [VFD Clock Stand.skp]
2015-07-19 Complete design for plastic stand.
    [VFD Clock Stand.skp]
2015-07-19 move mount holes to work well with plastic stand
    [vfd-clock-B_Cu.gbl, vfd-clock-B_Mask.gbs, vfd-clock-B_Paste.gbp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]
2015-07-19 fix missing silksreen text
    [vfd-clock-B_Cu.gbl, vfd-clock-B_Mask.gbs, vfd-clock-B_Paste.gbp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]
2015-07-20 screw joints for horizontal support
    [VFD Clock Stand.skp]
2015-07-21 fix transistor pin orientation
    [vfd-clock-B_Cu.gbl, vfd-clock-B_Mask.gbs, vfd-clock-B_Paste.gbp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]
2015-07-21 widen battery terminals for easier hand soldering
    [vfd-clock.kicad_pcb]
2015-07-21 fix buzzer pin width
    [vfd-clock.kicad_pcb]
2015-07-22 volt shifters ssop->tssop
    [vfd-clock.kicad_pcb, vfd-clock.sch]
2015-07-22 update gerbers
    [vfd-clock-B_Cu.gbl, vfd-clock-B_Mask.gbs, vfd-clock-B_Paste.gbp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]
2015-07-22 rotate power jacks for plug clearance
    [vfd-clock-B_Cu.gbl, vfd-clock-B_Mask.gbs, vfd-clock-B_Paste.gbp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]
2015-07-22 Add README, LICENSE, github link.
    [vfd-clock.kicad_pcb]
2015-07-22 realign logo text
    to miss recently moved power jack holes
    [vfd-clock-B_Cu.gbl, vfd-clock-B_Mask.gbs, vfd-clock-B_Paste.gbp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]
2015-07-24 Update maple mini but/led pins.
    [vfd-clock.sch]
2015-07-25 WIP working PWM output
2015-07-25 move grid/buz outputs to distinct PWM timer pins
    rearrange a few traces for better ground fill and some silkscreen text
    as well
    [vfd-clock.kicad_pcb, vfd-clock.sch]
2015-07-25 rounded corners
    [vfd-clock.kicad_pcb]
2015-07-25 various track tweaks
    [vfd-clock.kicad_pcb]
2015-07-25 updated gerbers
    [vfd-clock-B_Cu.gbl, vfd-clock-B_Mask.gbs, vfd-clock-B_Paste.gbp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]
2015-07-27 Coalesce RTC and Timer code.
2015-07-28 fix: expose copper/pull back solder mask around VFD pins on bottom layer
    [vfd-clock-B_Cu.gbl, vfd-clock-B_Mask.gbs, vfd-clock-B_Paste.gbp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]
2015-07-30 More efficient strobe pin setting.
2015-07-30 Shorter strobe delay.
    Driving at 20v instead of 3v3 means the chip requires less time to load the data pins.
    [main.c]
2015-08-01 Index gStrobePins correctly.
    The strobeLine value is 1-indexed (0 meaning none), so -1 to address the
    zero-indexed array!
    [main.c]
2015-08-02 Drive all five buttons via interrupts.
    TODO: debounce.
2015-08-02 Basic time setting via button handling
2015-08-03 fix values for a few passives
    [vfd-clock.sch]
2015-08-03 fix buzzer size layout
    [vfd-clock.kicad_pcb, vfd-clock.sch]
2015-08-06 Comletely disable the buzzer.
    It works! And I don't want it buzzing nonstop, until I write code to make it beep and bloop correctly.
    [main.c]
2015-08-06 Remove the once-per-second LED blink.
2015-08-06 Functional dim button.
2015-08-07 Update stand for power cord clearance.
    Also more space for screw (threads) to fit through in vertical legs.
    [VFD Clock Stand.skp]
2015-08-07 Faster systick interrupt.
    Used for:
    * Polling/debouncing buttons.
    * Blinking DP on half seconds.
    * Still blinking digit-to-set.
2015-08-07 Switch to external crystal for RTC.
2015-08-07 Regulator resistor divider value update.
    I picked the wrong base/pot values to set the regulator's output voltage; I can only set it from barely not too high to definitely too high.
    Switch to a relatively huge trimpot and a smaller base, to have a wider adjustment range.
    [vfd-clock.sch]
2015-08-08 Don't reset the RTC counter at boot.
    So the battery backup will work!
    [main.c]
2015-08-19 Try two: power-cord-compatible stand.
    After pushing so far back I decided to A) revert the left leg to how I
    started and B) loop around for more support in front of the cord. Also,
    both front feet are pulled forward for better tipping resistance. (Rear
    were positioned OK, but front were not out in front enough.)
    [VFD Clock Stand.skp]
2015-08-25 Clean up GPS handling.
    - Remove debugging LED light.
    - Maple button toggles GPS availability flag
    - Fix data poll ("frequency" value is only 0/1).
    - Correct utc offset display always.
    Also update release build.
    [main.c]
2017-01-02 Add BOM to README
    Plus some part/assembly notes.
2017-01-02 PNP transistors, not MOSFET
2017-01-02 Updated resistor values
2017-01-02 BOM update
    Mention the plug that mates with the jack, and that the battery is optional.

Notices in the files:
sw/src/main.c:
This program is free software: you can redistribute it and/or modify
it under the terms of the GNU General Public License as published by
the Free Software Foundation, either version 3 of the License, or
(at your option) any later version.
